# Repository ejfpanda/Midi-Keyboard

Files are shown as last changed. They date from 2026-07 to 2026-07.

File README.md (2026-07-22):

# Midi-Keyboard

## Overview

It has 20 keys, 2 rotary encoders, a digital-to-analog converter (I2S DAC), an sd card, LCD and uses a raspberry pi pico. You can use the rotary encoders to shift octaves and also change midi channels. The microcontroller is used to process user input into this midi keyboard.

## CAD



## PCB and schematic





## Required parts:

| Component | Amount |
| :--- | :---: |
| **Raspberry Pi Pico** | 1x |
| **MX-Style switches** | 21x |
| **1N4148 Diodes** | 20x |
| **EC11 Rotary encoder** | 2x |
| **Case** | 1x |
| **PCB** | 1x |
| **M3x25mm screws** | 4x |
| **PCM5100 I2S DAC** | 1x |
| **ST7735R** | 1x |
| **SD Card** | 1x |

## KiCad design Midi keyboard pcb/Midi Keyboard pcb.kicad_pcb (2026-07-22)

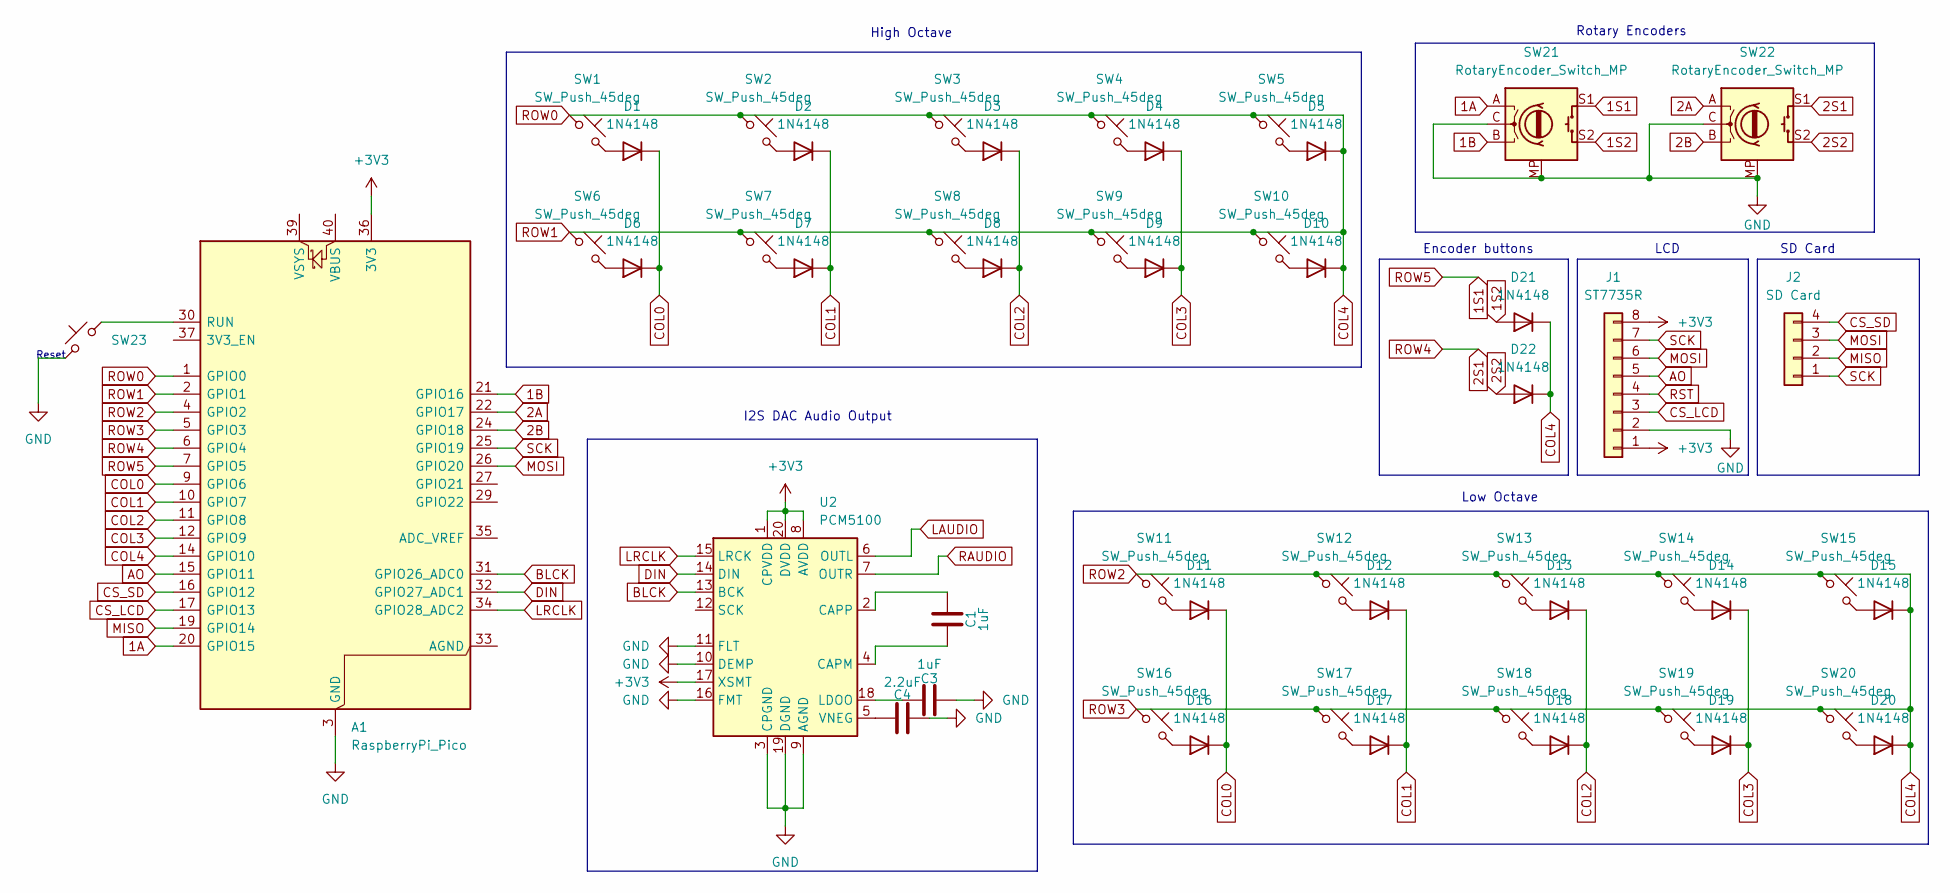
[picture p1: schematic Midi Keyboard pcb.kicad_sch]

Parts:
A1: RaspberryPi_Pico; RaspberryPi_Pico_Common_Unspecified
C1, C3: 1uF; CP_Axial_L10.0mm_D4.5mm_P15.00mm_Horizontal
C4: 2.2uF; CP_Axial_L10.0mm_D4.5mm_P15.00mm_Horizontal
D1, D2, D3, D4, D5, D6, D7, D8, D9, D10, D11, D12, D13, D14, D15, D16, D17, D18, D19, D20, D21, D22: 1N4148; D_DO-35_SOD27_P7.62mm_Horizontal
J1: ST7735R; PinSocket_1x08_P1.00mm_Vertical
J2: SD Card; PinSocket_1x04_P1.00mm_Vertical_SMD_Pin1Right
SW1, SW2, SW3, SW4, SW5, SW6, SW7, SW8, SW9, SW10, SW11, SW12, SW13, SW14, SW15, SW16, SW17, SW18, SW19, SW20: SW_Push_45deg; SW_Cherry_MX_1.00u_PCB
SW21, SW22: RotaryEncoder_Switch_MP; RotaryEncoder_Alps_EC11E-Switch_Vertical_H20mm
SW23: SW_Cherry_MX_1.00u_PCB
U2: PCM5100; SOP65P640X120-20N

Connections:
1A: A1.20 (GPIO15), SW21.A
1B: A1.21 (GPIO16), SW21.B
1S1: A1.7 (GPIO5), SW21.S1
1S2: D21.2 (A), SW21.S2
2A: A1.22 (GPIO17), SW22.A
2B: A1.24 (GPIO18), SW22.B
2S1: A1.6 (GPIO4), SW22.S1
2S2: D22.2 (A), SW22.S2
+3V3: A1.36 (3V3), J1.1, J1.8, U2.1 (CPVDD), U2.8 (AVDD), U2.17 (XSMT), U2.20 (DVDD)
AO: A1.15 (GPIO11), J1.5
BLCK: A1.31 (GPIO26_ADC0), U2.13 (BCK)
COL0: A1.9 (GPIO6), D1.1 (K), D6.1 (K), D11.1 (K), D16.1 (K)
COL1: A1.10 (GPIO7), D2.1 (K), D7.1 (K), D12.1 (K), D17.1 (K)
COL2: A1.11 (GPIO8), D3.1 (K), D8.1 (K), D13.1 (K), D18.1 (K)
COL3: A1.12 (GPIO9), D4.1 (K), D9.1 (K), D14.1 (K), D19.1 (K)
COL4: A1.1 (GPIO0), A1.2 (GPIO1), A1.4 (GPIO2), A1.5 (GPIO3), A1.14 (GPIO10), D5.1 (K), D10.1 (K), D15.1 (K), D20.1 (K), D21.1 (K), D22.1 (K), SW1.1, SW2.1, SW3.1, SW4.1, SW5.1, SW6.1, SW7.1, SW8.1, SW9.1, SW10.1, SW11.1, SW12.1, SW13.1, SW14.1, SW15.1, SW16.1, SW17.1, SW18.1, SW19.1, SW20.1
CS_LCD: A1.17 (GPIO13), J1.3
CS_SD: A1.16 (GPIO12), J2.4
DIN: A1.32 (GPIO27_ADC1), U2.14 (DIN)
GND: A1.3 (GND), A1.8 (GND), A1.13 (GND), A1.18 (GND), A1.23 (GND), A1.28 (GND), A1.38 (GND), C3.2, C4.2, J1.2, SW21.C, SW21.MP, SW22.C, SW22.MP, SW23.1, U2.3 (CPGND), U2.9 (AGND), U2.10 (DEMP), U2.11 (FLT), U2.16 (FMT), U2.19 (DGND)
LAUDIO: U2.6 (OUTL)
LRCLK: A1.34 (GPIO28_ADC2), U2.15 (LRCK)
MISO: A1.19 (GPIO14), J2.2
MOSI: A1.26 (GPIO20), J1.6, J2.3
unnamed: A1.30 (RUN), SW23.2
unnamed: D1.2 (A), SW1.2
unnamed: D2.2 (A), SW2.2
unnamed: D3.2 (A), SW3.2
unnamed: D4.2 (A), SW4.2
unnamed: D5.2 (A), SW5.2
unnamed: D6.2 (A), SW6.2
unnamed: D7.2 (A), SW7.2
unnamed: D8.2 (A), SW8.2
unnamed: D9.2 (A), SW9.2
unnamed: D10.2 (A), SW10.2
unnamed: D11.2 (A), SW11.2
unnamed: D12.2 (A), SW12.2
unnamed: D13.2 (A), SW13.2
unnamed: D14.2 (A), SW14.2
unnamed: D15.2 (A), SW15.2
unnamed: D16.2 (A), SW16.2
unnamed: D17.2 (A), SW17.2
unnamed: D18.2 (A), SW18.2
unnamed: D19.2 (A), SW19.2
unnamed: D20.2 (A), SW20.2
unnamed: C1.2, U2.4 (CAPM)
unnamed: C1.1, U2.2 (CAPP)
unnamed: C3.1, U2.18 (LDOO)
unnamed: C4.1, U2.5 (VNEG)
RAUDIO: U2.7 (OUTR)
RST: J1.4
SCK: A1.25 (GPIO19), J1.7, J2.1

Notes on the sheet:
SD Card
Reset
Rotary Encoders
Encoder buttons
I2S DAC Audio Output
Low Octave
High Octave
LCD

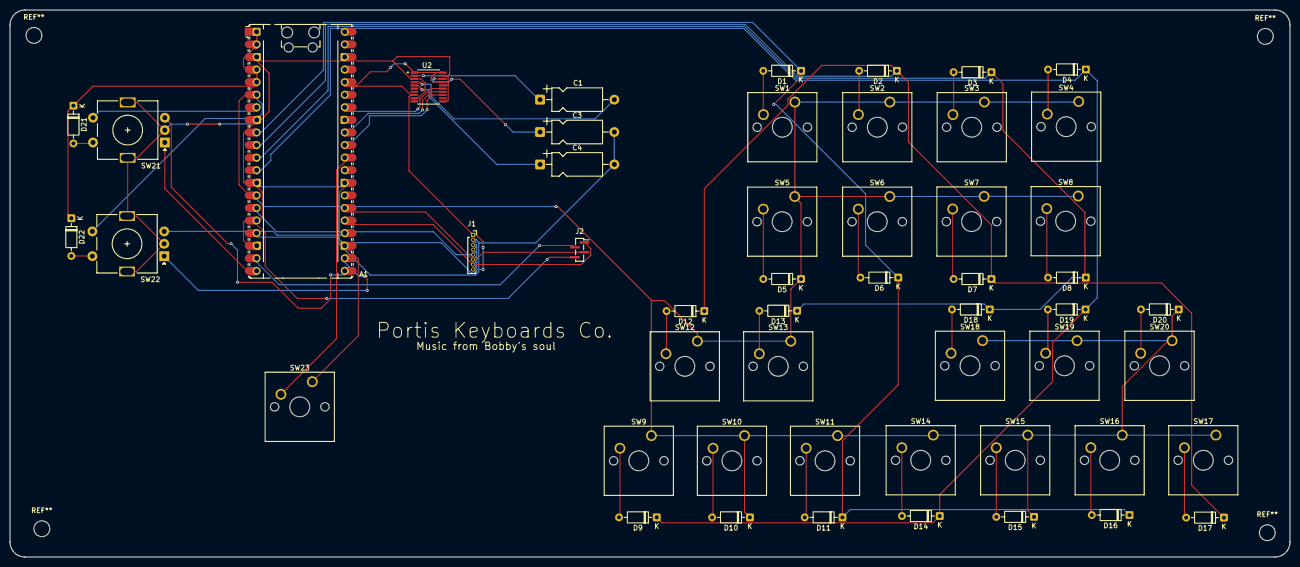
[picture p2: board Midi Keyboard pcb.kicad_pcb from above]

Board: 2 copper layers, 258.4 x 110.4 mm, 52 parts (0 on the bottom side), 49 nets.

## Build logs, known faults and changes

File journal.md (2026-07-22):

# Midi Keyboard

## Day 1 July 18th 2026 , Cumulative time: 2 Hours

I went into KiCad and added the raspberry pi pico and then connected the +3v3 and ground symbols.

Then I added 30 switches for now and 30 diodes to make matrix wiring.

I decided to split it with high octave keys and low octave keys.

I first did the high octave keys and went with 2 rows and 5 columns. 


The matrix wiring took me less time than my last project, as I didn't have to learn it all over again.

I then went ahead and made the low octave key matrix with 2 more rows and again 5 columns.


Next I put the global labels onto the raspberry pi pico.


I also added two rotary encoder switches and added the encoder button matrix.

I also put in an LCD and SD card using an 8 pin connector for LCD and 4 pin with SD card.


Then I tried to add in the I2S DAC, but I was researching it and was very confused on how to put the footprint and symbol in at first but got it eventually and I had to ask how to connect everything from a friend.


## Day 2 July 19th 2026, Cumulative time: 4.5 hours

I started this day almost into July 20th, so I was kinda tired.

I went over everything in the schematic because I still wasn't sure about everything.

Then I transferred the schematic over to the PCB editor.

This is the final schematic:



I had a tough time trying to organise everything because I wasn't sure what the best way was of connecting everything in a nice layout.

I settled on one way eventually and hammered at it for like 2 hours until I realised I had gone wrong somewhere because I couldn't find a way to get two components to route together.

The hard part was that some of my footprints were so small that you couldn't cram too many wires near or in it.

So I got stuck and then I gave up for the night.

## Day 3 July 20th 2026, Cumulative time: 8 hours

I remember this day was very frustrating because I'd spent like an hour rerouting everything twice but both times my computer crashed and I forgot to save.

So on the third time when I routed it I made sure to save every few seconds but then it just didn't crash.

I was very happy with the second time I routed it and a bit less happy with the final time but it's still ok.

Final PCB:



I then finished the day by adding 3D models to all of the components, getting it ready for export to CAD.



I also started the CAD for almost an hour. 

I started by doing the sketch for the base and importing the board, before suddenly realising I had forgotten mounting holes in the board, so I went back and did that.

## Day 4 July 21st 2026, Cumulative time: 12 hours

I continued with the CAD.

I made the base with mounting holes.

I then used a fastened mate to connect the base with the board.

The base has an indent along the inside, with the outsides extruded more so that the board can rest inside a border.

The outside is smooth due to the use of Fillet within Onshape.

I then proceeded with the lid.

At first I tried to leave most of the 3D parts uncovered, but then I realised that looked ugly.

My final plan was to raise the level of the lid by extruding the corners and then have only the keys, the rotary encoders and the raspberry pi pico sticking out.

I also removed a section of the base of the board and lid which covered the USB.

This was the final CAD:



## Day 5 July 22nd 2026, Cumulative time: ?? hours

Today, I made the firmware code.

I added the key matrix.

I added the fact that one of the rotary encoders changed the octave, and the other changed the midi channel.

I also added the LCD code for the display and the background, with labels which updated with octave shifts and channel changes.

Finally the main loop, where the midi was notified of key presses.

Also there is a time.sleep of 0.001 for a delay in order to prevent CPU overload.

See firmware code in repo.

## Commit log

2026-07-22 Add pcb and firmware code
    [Midi Keyboard pcb.kicad_pcb, Midi Keyboard pcb.kicad_sch]
2026-07-22 Add Pico
